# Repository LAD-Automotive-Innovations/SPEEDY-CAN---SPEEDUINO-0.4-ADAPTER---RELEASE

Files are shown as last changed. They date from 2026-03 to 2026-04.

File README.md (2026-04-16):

# SPEEDY-CAN - SPEEDUINO 0.4 ADAPTER - RELEASE
A universal 35 pin adapter for the Speeduino 0.4 Ecu's

This is an easy to assemble pcb for the speeduino series ecu's.

The goal is to have an all in one pcb with the ability to have - 

A - CanBus output via esp32

B - Lamp outputs for features such as check engine light, Rpm limit, launch control illumination etc.

C - Avaliable inputs for oil/fuel pressure, vss etc.

D - Cheap to produce. (meet the 10x10 format) 

E - Easy to assemble using cheap existing modules and few components.

This can be used as a regular adapter without any need for moduleds or coding or logic.. it is simply there as an addition.

This is an early release, There is currently no coding avaliable. 

I have supplied information relative to pinouts required for your code.

There are existing speeduino canbus scripts that have useful information/code. (speeduino to realdash/serial2can etc) 

Treate it as an opensource community project. I have provided the bones.

UPDATE: after much testing, I have a prototype enclosure ready. 

Waiting for the 30-pin amp connector to confirm front alignment, but everything else has been fitment tested and is spot on. 

The enclosure has been made in a way where it's easy to print, and parts are replaceable or changes can be adapted without having to reprint an entire unit. 

2x side plates act as a jig to make sure the 40-pin connector is aligned correctly. 

The base has access to the esp32 boot and reset pins. Access to the USB port is there as well.

ENJOY!

Enjoy! - Automotive Innovations.










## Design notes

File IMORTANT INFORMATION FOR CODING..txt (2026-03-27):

IMORTANT INFORMATION FOR CODING.

MEGA SERIAL 3 - ESP32 -
RX - 17
TX - 16

LAMP MOSFET - ESP32 OUTPUT PINS - 
LAMP 1 - 14
LAMP 2 - 13
LAMP 3 - 21
LAMP 4 - 22
LAMP 5 - 27
LAMP 6 - 26
LAMP 7 - 25
LAMP 8 - 33

MCP2515 TO ESP32 - 
INT - 4
SCK - 18
SI - 23
SO - 19
CS - 5

Cluster illumination MOSFETs switch to GND1 (not chassis)
MCP2515 CS has a pull-up to 3V
MCP2515 INT is pulled up to 3V3 (open-drain interrupt)
UART Mega TX to ESP RX uses a divider. ESP TX to Mega RX is direct

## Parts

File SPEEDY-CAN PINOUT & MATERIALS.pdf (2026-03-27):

PIN | FUNCTION | COMMENTS | NOTES
1 | INJECTOR - 1
2 | INJECTOR - 2
3 | INJECTOR - 3
4 | INJECTOR - 4
5 | IGNITION - 1
6 | IGNITION - 4
7 | IGNITION - 3
8 | IGNITION - 2
9 | BOOST OUT
10 | VVT
11 | IDLE - 2
12 | PWM IDLE
13 | FLEX FUEL
14 | RADIATOR FAN - OUT
15 | CLUTCH SWITCH
16 | IAT SENSOR
17 | WB02 SENSOR
18 | CRANK IN
19 | VR1 -
20 | 5V - OUT
21 | STEPPER - A1
22 | STEPPER - A2
23 | ECU GND - IN
24 | GND - OUT
25 | EXT. MAP
26 | FUEL PUMP - OUT
27 | TACHO - OUT
28 | CLT SENSOR
29 | TPS SENSOR
30 | CAM - IN
31 | VR2 -
32 | GND - OUT
33 | STEPPER - B2
34 | STEPPER - B1
35 | 12V - ECU LIVE - IN

# SPEEDUINO 0.4 ECU PINOUT

## 35 PIN - AMP CONNECTOR

PIN | FUNCTION | COMMENTS | NOTES
1 | CAN - H
2 | LAMP - 5/SPARE INPUT | | SOLDER JUMPER FOR LAMP OUTPUT
3 | LAMP - 6/SPARE INPUT | | SOLDER JUMPER FOR LAMP OUTPUT
4 | LAMP - 7/SPARE INPUT | | SOLDER JUMPER FOR LAMP OUTPUT
5 | LAMP - 8/SPARE INPUT | | SOLDER JUMPER FOR LAMP OUTPUT
6 | SPARE INPUT
7 | CAN - L
8 | LAMP - 4
9 | LAMP - 3
10 | LAMP - 2
11 | LAMP - 1
12 | SPARE INPUT

## If suffering with voltage issues onboard the PCB. Please do the following -Solder wire jumpers across - 5VA Main - To 5VB & 5VC And so on. (J1,J2,J3)

Solder wire jumpers across - GND1A Main - To GND1B & GND1C And so on. (J4,J5,J6) DO NOT CONNECT TO J10 GND. THIS IS ECU INPUT (BODY/CHASSIS).

Solder TX & RX To Mega Serial 3. Solder J10 - 12V And GND To Speeduino Voltage Inputs.

# 12 PIN - CONNECTOR

# Notes:

Lamp outputs ideal for Check engine light, Rpm limits, Launch control, Temperature warnings etc. Spare inputs (J7,J8) ideal for features such as VSS, Oil pressure and other optional inputs. CAN LOW/HIGH - Canbus output for digital clusters and gauges.

PRODUCT | QUANTITY | PLACEMENT | NOTES | LINK
ESP32 WROOM32 DEVKIT C 30PIN | X1 | U2 | | https://www.aliexpress.com/item/1005006476900011.html
MCP2515 CAN MODULE | X1 | U1 | | https://www.aliexpress.com/item/1005006646252397.html
JAE MX23A12NF1 | X1 | CN2 | 12-PIN CONNECTOR | https://www.aliexpress.com/item/1005010178343640.html
FEMALE IDC HEADER 2x20 P2.54MM | X1 | CN3 | FEMALE HEADER TO SPEEDUINO | https://www.aliexpress.com/item/1005008966856219.html
TYCO AMPSEAL 776164-1 ANGLE | X1 | CN1 | 35-PIN CONNECTOR | https://www.aliexpress.com/item/1005003107028993.html
AO3400A SOT-23 MOSFETS | X8 | Q1 - TO - Q8 | FOR LAMP LOGIC | https://www.aliexpress.com/item/1005009307642127.html
0603 10K 4X RESISTOR ARRAY | X2 | RN3,RN4 | NETWORK ARRAY | https://www.aliexpress.com/item/1005007204291786.html
0603 1K 4X RESISTOR ARRAY | X2 | RN1,RN2 | NETWORK ARRAY | https://www.aliexpress.com/item/1005007204291786.html
0603 10K RESISTOR'S | X2 | R1,R4 | | SAME LINK AS BELOW
0603 20K RESISTOR'S | X2 | R2,R5 | | https://www.aliexpress.com/item/1005002991861666.html
0603 47K RESISTOR'S | X2 | R3,R6 | | SAME LINK AS ABOVE
MALE 2.54 HEADERS | | CUT TO SIZE | | https://www.aliexpress.com/item/1005009370767269.html

## 12 PIN - CONNECTOR

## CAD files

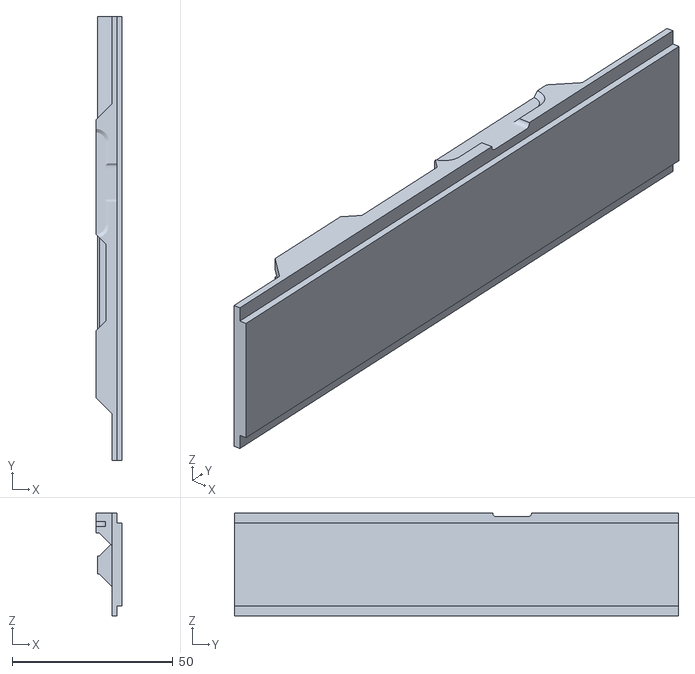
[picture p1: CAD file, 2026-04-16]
PROTOTYPE ENCLOSURE/RIGHT PLATE.stl
8.00 x 138.0 x 31.9

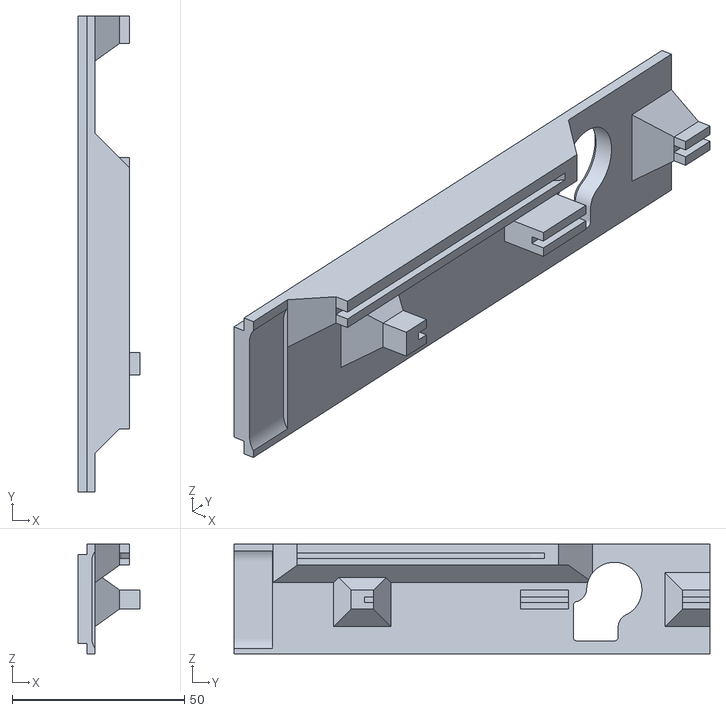
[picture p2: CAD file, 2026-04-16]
PROTOTYPE ENCLOSURE/LEFT PLATE.stl
18.0 x 138.0 x 31.9

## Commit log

2026-03-27 Enhance README with detailed adapter information
    Expanded the README to provide detailed information about the Speeduino 0.4 adapter, including features and assembly instructions.
2026-04-13 3d enclosure files added.
2026-04-16 Add prototype enclosure details to README
    Updated the README with details about the prototype enclosure and its features.
